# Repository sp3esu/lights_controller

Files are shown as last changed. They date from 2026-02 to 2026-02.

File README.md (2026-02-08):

# RC Light Controller

Wireless light controller for RC cars and trucks. A touchscreen handheld remote (TX) communicates over ESP-NOW with a receiver (RX) mounted on the vehicle to control multiple light outputs in real time.

## Translations

- [Polski (PL)](docs/README_PL.md)
- [Deutsch (DE)](docs/README_DE.md)
- [Francais (FR)](docs/README_FR.md)
- [Русский (RU)](docs/README_RU.md)
- [Українська (UA)](docs/README_UA.md)

## Features

- **5 independent light channels**: low beam, high beam, fog lights, light bar, hazard lights
- **Touchscreen UI**: 2x3 button grid on a 1.47" color display with LVGL
- **ESP-NOW wireless**: low-latency, connectionless protocol — no WiFi router needed
- **Automatic pairing**: one-button pairing with persistent NVS storage
- **Safety interlocks**: high beam requires low beam; failsafe shuts off all lights after 30s without signal
- **Connection monitoring**: heartbeats, ACK-based command confirmation, NeoPixel status LED
- **Test mode**: controller works standalone for UI testing without a receiver

## Hardware

### Controller (TX)

| Component | Details |
|---|---|
| Board | [Waveshare ESP32-C6-Touch-LCD-1.47-M](https://www.waveshare.com/wiki/ESP32-C6-Touch-LCD-1.47) |
| MCU | ESP32-C6 (RISC-V, 8 MB flash) |
| Display | 1.47" JD9853, 172x320, rotated to 320x172 landscape |
| Touch | AXS5106L capacitive (I2C @ 0x63) |
| Status LED | WS2812 NeoPixel on GPIO8 |

### Receiver (RX)

| Component | Details |
|---|---|
| Board | Any ESP32 dev board (classic Xtensa) |
| Light outputs | 5x GPIO, active-HIGH |
| Status LED | Built-in LED on GPIO2 |
| Pairing | BOOT button (GPIO0) — hold during power-up |

### Receiver Wiring

Connect ESP32 GPIOs to your lights through appropriate drivers (MOSFETs, relays, or LED drivers) depending on voltage and current requirements. All outputs are active-HIGH (3.3 V logic).

| GPIO | Function |
|---|---|
| 16 | Fog lights |
| 17 | Low beam |
| 18 | High beam |
| 19 | Light bar |
| 21 | Hazard lights |
| 2 | Status LED |
| 0 | Pairing button (BOOT) |

## Building & Flashing

### Prerequisites

- [PlatformIO](https://platformio.org/) (CLI or IDE plugin)
- USB cables for both boards

### Build

```bash
# Build controller (TX) firmware
pio run -e controller

# Build receiver (RX) firmware
pio run -e receiver
```

### Flash

```bash
# Flash controller
pio run -e controller -t upload

# Flash receiver
pio run -e receiver -t upload
```

### Serial Monitor

```bash
pio device monitor    # 115200 baud
```

## Pairing

1. Power on the **receiver** while holding the **BOOT button** (GPIO0). The status LED flashes 3 times to confirm pairing mode.
2. On the **controller**, open **Settings** and tap **Start Pairing**.
3. Both devices exchange MAC addresses over ESP-NOW broadcast and store them in NVS.
4. Power-cycle both devices. The pairing is persistent and survives reboots.

## Protocol

Communication uses ESP-NOW with packed C structs (`__attribute__((packed))`) for cross-architecture compatibility (RISC-V controller / Xtensa receiver).

| Message | Direction | Purpose |
|---|---|---|
| `LightCommand` | TX -> RX | Set light state (5-bit bitmask) |
| `LightAck` | RX -> TX | Confirm current state |
| `Heartbeat` | RX -> TX | Keep-alive (every 2 s) |
| `StateReport` | RX -> TX | Full state + uptime |
| `PairRequest` | TX -> RX | Broadcast pairing request |
| `PairResponse` | RX -> TX | Pairing response with MAC |

### Light Bitmask

| Bit | Light |
|-----|---|
| 0 | Fog lights |
| 1 | Low beam |
| 2 | High beam |
| 3 | Light bar |
| 4 | Hazard lights |

### Timing

| Parameter | Value |
|---|---|
| ACK timeout | 200 ms |
| Max retries | 3 |
| Heartbeat interval | 2 s |
| Connection timeout (TX) | 6 s |
| Failsafe timeout (RX) | 30 s |

## Project Structure

```
light_controller/
├── src/
│   ├── controller/      # TX: display, touch, LVGL UI, ESP-NOW TX
│   └── receiver/        # RX: GPIO outputs, ESP-NOW RX, failsafe
├── lib/
│   ├── protocol/        # Shared wire protocol definitions
│   └── axs5106l_touch/  # AXS5106L touch driver
├── include/
│   └── lv_conf.h        # LVGL 8.4 configuration
└── platformio.ini       # Build configuration (two environments)
```

## Dependencies

### Controller
- [LVGL 8.4](https://lvgl.io/) — touchscreen UI framework
- [Arduino_GFX 1.6.5](https://github.com/moononournation/Arduino_GFX) — display driver
- [FastLED 3.9](https://fastled.io/) — NeoPixel status LED

### Receiver
- ESP-IDF built-ins only (ESP-NOW, WiFi, Preferences)

## License

This project is open source. See [LICENSE](LICENSE) for details.

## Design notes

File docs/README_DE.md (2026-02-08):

# RC-Lichtsteuerung

[English](../README.md) | [Polski](README_PL.md) | **Deutsch** | [Francais](README_FR.md) | [Русский](README_RU.md) | [Українська](README_UA.md)

Kabellose Lichtsteuerung fuer RC-Autos und -Trucks. Eine Touchscreen-Fernbedienung (TX) kommuniziert ueber ESP-NOW mit einem am Fahrzeug montierten Empfaenger (RX) zur Echtzeit-Steuerung mehrerer Lichtausgaenge.

## Funktionen

- **5 unabhaengige Lichtkanaele**: Abblendlicht, Fernlicht, Nebelscheinwerfer, Lichtleiste, Warnblinker
- **Touchscreen-Oberflaeche**: 2x3-Tastenraster auf einem 1,47"-Farbdisplay mit LVGL
- **ESP-NOW-Funk**: Protokoll mit geringer Latenz — kein WLAN-Router erforderlich
- **Automatisches Pairing**: Ein-Tasten-Kopplung mit dauerhafter NVS-Speicherung
- **Sicherheitsverriegelungen**: Fernlicht erfordert Abblendlicht; Failsafe schaltet alle Lichter nach 30 s ohne Signal ab
- **Verbindungsueberwachung**: Heartbeats, ACK-basierte Befehlsbestaetigung, NeoPixel-Status-LED
- **Testmodus**: Controller funktioniert eigenstaendig ohne Empfaenger

## Hardware

### Controller (TX)

| Komponente | Details |
|---|---|
| Platine | [Waveshare ESP32-C6-Touch-LCD-1.47-M](https://www.waveshare.com/wiki/ESP32-C6-Touch-LCD-1.47) |
| MCU | ESP32-C6 (RISC-V, 8 MB Flash) |
| Display | 1,47" JD9853, 172x320, auf 320x172 Querformat gedreht |
| Touch | AXS5106L kapazitiv (I2C @ 0x63) |
| Status-LED | WS2812 NeoPixel an GPIO8 |

### Empfaenger (RX)

| Komponente | Details |
|---|---|
| Platine | Beliebiges ESP32-Entwicklungsboard (klassisches Xtensa) |
| Lichtausgaenge | 5x GPIO, aktiv-HIGH |
| Status-LED | Eingebaute LED an GPIO2 |
| Pairing | BOOT-Taste (GPIO0) — beim Einschalten gedrueckt halten |

### Empfaenger-Verkabelung

Verbinden Sie die ESP32-GPIOs ueber geeignete Treiber (MOSFETs, Relais oder LED-Treiber) mit Ihren Lichtern, je nach Spannungs- und Stromanforderungen. Alle Ausgaenge sind aktiv-HIGH (3,3-V-Logik).

| GPIO | Funktion |
|---|---|
| 16 | Nebelscheinwerfer |
| 17 | Abblendlicht |
| 18 | Fernlicht |
| 19 | Lichtleiste |
| 21 | Warnblinker |
| 2 | Status-LED |
| 0 | Pairing-Taste (BOOT) |

## Kompilieren & Flashen

### Voraussetzungen

- [PlatformIO](https://platformio.org/) (CLI oder IDE-Plugin)
- USB-Kabel fuer beide Platinen

### Kompilieren

```bash
# Controller-Firmware (TX) kompilieren
pio run -e controller

# Empfaenger-Firmware (RX) kompilieren
pio run -e receiver
```

### Flashen

```bash
# Controller flashen
pio run -e controller -t upload

# Empfaenger flashen
pio run -e receiver -t upload
```

### Serieller Monitor

```bash
pio device monitor    # 115200 Baud
```

## Pairing

1. Schalten Sie den **Empfaenger** ein und halten Sie dabei die **BOOT-Taste** (GPIO0) gedrueckt. Die Status-LED blinkt 3 Mal zur Bestaetigung des Pairing-Modus.
2. Oeffnen Sie auf dem **Controller** die **Einstellungen** und tippen Sie auf **Pairing starten**.
3. Beide Geraete tauschen MAC-Adressen ueber ESP-NOW-Broadcast aus und speichern sie im NVS.
4. Starten Sie beide Geraete neu. Das Pairing ist dauerhaft und uebersteht Neustarts.

## Protokoll

Die Kommunikation verwendet ESP-NOW mit gepackten C-Structs (`__attribute__((packed))`) fuer architekturuebergreifende Kompatibilitaet (RISC-V-Controller / Xtensa-Empfaenger).

| Nachricht | Richtung | Zweck |
|---|---|---|
| `LightCommand` | TX -> RX | Lichtzustand setzen (5-Bit-Maske) |
| `LightAck` | RX -> TX | Aktuellen Zustand bestaetigen |
| `Heartbeat` | RX -> TX | Verbindungserhaltung (alle 2 s) |
| `StateReport` | RX -> TX | Vollstaendiger Zustand + Betriebszeit |
| `PairRequest` | TX -> RX | Pairing-Anfrage (Broadcast) |
| `PairResponse` | RX -> TX | Pairing-Antwort mit MAC |

### Licht-Bitmaske

| Bit | Licht |
|-----|---|
| 0 | Nebelscheinwerfer |
| 1 | Abblendlicht |
| 2 | Fernlicht |
| 3 | Lichtleiste |
| 4 | Warnblinker |

### Zeitvorgaben

| Parameter | Wert |
|---|---|
| ACK-Timeout | 200 ms |
| Max. Wiederholungen | 3 |
| Heartbeat-Intervall | 2 s |
| Verbindungs-Timeout (TX) | 6 s |
| Failsafe-Timeout (RX) | 30 s |

## Projektstruktur

```
light_controller/
├── src/
│   ├── controller/      # TX: Display, Touch, LVGL-UI, ESP-NOW TX
│   └── receiver/        # RX: GPIO-Ausgaenge, ESP-NOW RX, Failsafe
├── lib/
│   ├── protocol/        # Gemeinsame Protokolldefinitionen
│   └── axs5106l_touch/  # AXS5106L-Touch-Treiber
├── include/
│   └── lv_conf.h        # LVGL 8.4 Konfiguration
└── platformio.ini       # Build-Konfiguration (zwei Umgebungen)
```

## Abhaengigkeiten

### Controller
- [LVGL 8.4](https://lvgl.io/) — Touchscreen-UI-Framework
- [Arduino_GFX 1.6.5](https://github.com/moononournation/Arduino_GFX) — Display-Treiber
- [FastLED 3.9](https://fastled.io/) — NeoPixel-Status-LED

### Empfaenger
- Nur ESP-IDF-Bordmittel (ESP-NOW, WiFi, Preferences)

## Lizenz

Dieses Projekt ist Open Source. Details siehe [LICENSE](../LICENSE).

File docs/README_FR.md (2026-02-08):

# Controleur d'eclairage RC

[English](../README.md) | [Polski](README_PL.md) | [Deutsch](README_DE.md) | **Francais** | [Русский](README_RU.md) | [Українська](README_UA.md)

Controleur d'eclairage sans fil pour voitures et camions RC. Une telecommande a ecran tactile (TX) communique via ESP-NOW avec un recepteur (RX) monte sur le vehicule pour controler plusieurs sorties lumineuses en temps reel.

## Fonctionnalites

- **5 canaux lumineux independants** : feux de croisement, feux de route, antibrouillards, barre lumineuse, feux de detresse
- **Interface tactile** : grille de boutons 2x3 sur un ecran couleur 1,47" avec LVGL
- **Communication ESP-NOW** : protocole a faible latence — aucun routeur WiFi necessaire
- **Appairage automatique** : appairage en un bouton avec stockage persistant NVS
- **Verrouillages de securite** : les feux de route necessitent les feux de croisement ; le mode securite eteint toutes les lumieres apres 30 s sans signal
- **Surveillance de connexion** : heartbeats, confirmation de commandes par ACK, LED NeoPixel de statut
- **Mode test** : le controleur fonctionne de maniere autonome sans recepteur

## Materiel

### Controleur (TX)

| Composant | Details |
|---|---|
| Carte | [Waveshare ESP32-C6-Touch-LCD-1.47-M](https://www.waveshare.com/wiki/ESP32-C6-Touch-LCD-1.47) |
| MCU | ESP32-C6 (RISC-V, 8 Mo flash) |
| Ecran | 1,47" JD9853, 172x320, pivote en 320x172 paysage |
| Tactile | AXS5106L capacitif (I2C @ 0x63) |
| LED de statut | WS2812 NeoPixel sur GPIO8 |

### Recepteur (RX)

| Composant | Details |
|---|---|
| Carte | Toute carte de developpement ESP32 (Xtensa classique) |
| Sorties lumineuses | 5x GPIO, actif-HAUT |
| LED de statut | LED integree sur GPIO2 |
| Appairage | Bouton BOOT (GPIO0) — maintenir a l'allumage |

### Cablage du recepteur

Connectez les GPIO de l'ESP32 a vos lumieres via des pilotes appropries (MOSFETs, relais ou pilotes LED) selon les exigences de tension et de courant. Toutes les sorties sont actif-HAUT (logique 3,3 V).

| GPIO | Fonction |
|---|---|
| 16 | Antibrouillards |
| 17 | Feux de croisement |
| 18 | Feux de route |
| 19 | Barre lumineuse |
| 21 | Feux de detresse |
| 2 | LED de statut |
| 0 | Bouton d'appairage (BOOT) |

## Compilation et flashage

### Prerequis

- [PlatformIO](https://platformio.org/) (CLI ou plugin IDE)
- Cables USB pour les deux cartes

### Compilation

```bash
# Compiler le firmware du controleur (TX)
pio run -e controller

# Compiler le firmware du recepteur (RX)
pio run -e receiver
```

### Flashage

```bash
# Flasher le controleur
pio run -e controller -t upload

# Flasher le recepteur
pio run -e receiver -t upload
```

### Moniteur serie

```bash
pio device monitor    # 115200 bauds
```

## Appairage

1. Allumez le **recepteur** en maintenant le **bouton BOOT** (GPIO0). La LED de statut clignote 3 fois pour confirmer le mode d'appairage.
2. Sur le **controleur**, ouvrez les **Parametres** et appuyez sur **Demarrer l'appairage**.
3. Les appareils echangent leurs adresses MAC via broadcast ESP-NOW et les stockent en NVS.
4. Redemarrez les deux appareils. L'appairage est persistant et survit aux redemarrages.

## Protocole

La communication utilise ESP-NOW avec des structures C compactees (`__attribute__((packed))`) pour la compatibilite inter-architectures (controleur RISC-V / recepteur Xtensa).

| Message | Direction | Fonction |
|---|---|---|
| `LightCommand` | TX -> RX | Definir l'etat des lumieres (masque 5 bits) |
| `LightAck` | RX -> TX | Confirmer l'etat actuel |
| `Heartbeat` | RX -> TX | Maintien de connexion (toutes les 2 s) |
| `StateReport` | RX -> TX | Etat complet + duree de fonctionnement |
| `PairRequest` | TX -> RX | Demande d'appairage (broadcast) |
| `PairResponse` | RX -> TX | Reponse d'appairage avec MAC |

### Masque binaire des lumieres

| Bit | Lumiere |
|-----|---|
| 0 | Antibrouillards |
| 1 | Feux de croisement |
| 2 | Feux de route |
| 3 | Barre lumineuse |
| 4 | Feux de detresse |

### Temporisations

| Parametre | Valeur |
|---|---|
| Timeout ACK | 200 ms |
| Essais max. | 3 |
| Intervalle heartbeat | 2 s |
| Timeout de connexion (TX) | 6 s |
| Timeout de securite (RX) | 30 s |

## Structure du projet

```
light_controller/
├── src/
│   ├── controller/      # TX : ecran, tactile, UI LVGL, ESP-NOW TX
│   └── receiver/        # RX : sorties GPIO, ESP-NOW RX, mode securite
├── lib/
│   ├── protocol/        # Definitions de protocole partagees
│   └── axs5106l_touch/  # Pilote tactile AXS5106L
├── include/
│   └── lv_conf.h        # Configuration LVGL 8.4
└── platformio.ini       # Configuration de compilation (deux environnements)
```

## Dependances

### Controleur
- [LVGL 8.4](https://lvgl.io/) — framework d'interface tactile
- [Arduino_GFX 1.6.5](https://github.com/moononournation/Arduino_GFX) — pilote d'ecran
- [FastLED 3.9](https://fastled.io/) — LED NeoPixel de statut

### Recepteur
- Uniquement les composants integres ESP-IDF (ESP-NOW, WiFi, Preferences)

## Licence

Ce projet est open source. Voir [LICENSE](../LICENSE) pour les details.

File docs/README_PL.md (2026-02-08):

# Kontroler Oswietlenia RC

[English](../README.md) | **Polski** | [Deutsch](README_DE.md) | [Francais](README_FR.md) | [Русский](README_RU.md) | [Українська](README_UA.md)

Bezprzewodowy kontroler oswietlenia do samochodow i ciezarowek RC. Reczny pilot z ekranem dotykowym (TX) komunikuje sie przez ESP-NOW z odbiornikiem (RX) zamontowanym w pojezdzie, sterujac wieloma wyjsciami swietlnymi w czasie rzeczywistym.

## Funkcje

- **5 niezaleznych kanalow swiatla**: swiatla mijania, swiatla drogowe, swiatla przeciwmgielne, listwa swietlna, swiatla awaryjne
- **Interfejs dotykowy**: siatka przyciskow 2x3 na kolorowym wyswietlaczu 1,47" z LVGL
- **Lacznosc bezprzewodowa ESP-NOW**: protokol o niskim opoznieniu, bez potrzeby routera WiFi
- **Automatyczne parowanie**: parowanie jednym przyciskiem z trwalym zapisem w NVS
- **Blokady bezpieczenstwa**: swiatla drogowe wymagaja wlaczonych swiatel mijania; tryb awaryjny wylacza wszystkie swiatla po 30 s bez sygnalu
- **Monitorowanie polaczenia**: heartbeaty, potwierdzenia ACK, dioda LED NeoPixel
- **Tryb testowy**: kontroler dziala samodzielnie bez odbiornika

## Sprzet

### Kontroler (TX)

| Element | Szczegoly |
|---|---|
| Plytka | [Waveshare ESP32-C6-Touch-LCD-1.47-M](https://www.waveshare.com/wiki/ESP32-C6-Touch-LCD-1.47) |
| MCU | ESP32-C6 (RISC-V, 8 MB flash) |
| Wyswietlacz | 1,47" JD9853, 172x320, obrocony do 320x172 poziomo |
| Dotyk | AXS5106L pojemnosciowy (I2C @ 0x63) |
| Dioda statusu | WS2812 NeoPixel na GPIO8 |

### Odbiornik (RX)

| Element | Szczegoly |
|---|---|
| Plytka | Dowolna plytka ESP32 (klasyczny Xtensa) |
| Wyjscia swiatla | 5x GPIO, aktywne-WYSOKO |
| Dioda statusu | Wbudowana LED na GPIO2 |
| Parowanie | Przycisk BOOT (GPIO0) — przytrzymaj przy wlaczaniu |

### Polaczenia odbiornika

Podlacz GPIO ESP32 do swiatel przez odpowiednie sterowniki (MOSFET-y, przekazniki lub sterowniki LED) w zaleznosci od napiecia i pradu. Wszystkie wyjscia sa aktywne-WYSOKO (logika 3,3 V).

| GPIO | Funkcja |
|---|---|
| 16 | Swiatla przeciwmgielne |
| 17 | Swiatla mijania |
| 18 | Swiatla drogowe |
| 19 | Listwa swietlna |
| 21 | Swiatla awaryjne |
| 2 | Dioda statusu |
| 0 | Przycisk parowania (BOOT) |

## Kompilacja i programowanie

### Wymagania

- [PlatformIO](https://platformio.org/) (CLI lub wtyczka IDE)
- Kable USB do obu plytek

### Kompilacja

```bash
# Kompilacja firmware kontrolera (TX)
pio run -e controller

# Kompilacja firmware odbiornika (RX)
pio run -e receiver
```

### Programowanie

```bash
# Programowanie kontrolera
pio run -e controller -t upload

# Programowanie odbiornika
pio run -e receiver -t upload
```

### Monitor szeregowy

```bash
pio device monitor    # 115200 baud
```

## Parowanie

1. Wlacz **odbiornik** przytrzymujac **przycisk BOOT** (GPIO0). Dioda statusu mrugnie 3 razy potwierdzajac tryb parowania.
2. Na **kontrolerze** wejdz w **Ustawienia** i dotknij **Rozpocznij parowanie**.
3. Urzadzenia wymieniaja adresy MAC przez broadcast ESP-NOW i zapisuja je w NVS.
4. Zrestartuj oba urzadzenia. Parowanie jest trwale i przetrwa ponowne uruchomienie.

## Protokol

Komunikacja uzywa ESP-NOW z upakowanymi strukturami C (`__attribute__((packed))`) dla kompatybilnosci miedzy architekturami (RISC-V kontroler / Xtensa odbiornik).

| Wiadomosc | Kierunek | Cel |
|---|---|-----|
| `LightCommand` | TX -> RX | Ustaw stan swiatel (maska 5-bitowa) |
| `LightAck` | RX -> TX | Potwierdz aktualny stan |
| `Heartbeat` | RX -> TX | Podtrzymanie polaczenia (co 2 s) |
| `StateReport` | RX -> TX | Pelny stan + czas pracy |
| `PairRequest` | TX -> RX | Zadanie parowania (broadcast) |
| `PairResponse` | RX -> TX | Odpowiedz parowania z MAC |

### Maska bitowa swiatel

| Bit | Swiatlo |
|-----|---|
| 0 | Swiatla przeciwmgielne |
| 1 | Swiatla mijania |
| 2 | Swiatla drogowe |
| 3 | Listwa swietlna |
| 4 | Swiatla awaryjne |

### Czasy

| Parametr | Wartosc |
|---|---|
| Timeout ACK | 200 ms |
| Maks. powtorzen | 3 |
| Interwal heartbeat | 2 s |
| Timeout polaczenia (TX) | 6 s |
| Timeout awaryjny (RX) | 30 s |

## Struktura projektu

```
light_controller/
├── src/
│   ├── controller/      # TX: wyswietlacz, dotyk, UI LVGL, ESP-NOW TX
│   └── receiver/        # RX: wyjscia GPIO, ESP-NOW RX, tryb awaryjny
├── lib/
│   ├── protocol/        # Wspoldzielone definicje protokolu
│   └── axs5106l_touch/  # Sterownik dotyku AXS5106L
├── include/
│   └── lv_conf.h        # Konfiguracja LVGL 8.4
└── platformio.ini       # Konfiguracja kompilacji (dwa srodowiska)
```

## Zaleznosci

### Kontroler
- [LVGL 8.4](https://lvgl.io/) — framework UI ekranu dotykowego
- [Arduino_GFX 1.6.5](https://github.com/moononournation/Arduino_GFX) — sterownik wyswietlacza
- [FastLED 3.9](https://fastled.io/) — dioda statusu NeoPixel

### Odbiornik
- Tylko wbudowane komponenty ESP-IDF (ESP-NOW, WiFi, Preferences)

## Licencja

Ten projekt jest open source. Szczegoly w pliku [LICENSE](../LICENSE).

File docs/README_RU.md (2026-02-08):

# Контроллер освещения RC

[English](../README.md) | [Polski](README_PL.md) | [Deutsch](README_DE.md) | [Francais](README_FR.md) | **Русский** | [Українська](README_UA.md)

Беспроводной контроллер освещения для RC-автомобилей и грузовиков. Ручной пульт с сенсорным экраном (TX) связывается через ESP-NOW с приёмником (RX), установленным на модели, для управления несколькими световыми выходами в реальном времени.

## Возможности

- **5 независимых световых каналов**: ближний свет, дальний свет, противотуманные фары, световая балка, аварийная сигнализация
- **Сенсорный интерфейс**: сетка кнопок 2x3 на цветном дисплее 1,47" с LVGL
- **Беспроводная связь ESP-NOW**: протокол с низкой задержкой — WiFi-роутер не нужен
- **Автоматическое сопряжение**: сопряжение одной кнопкой с сохранением в NVS
- **Блокировки безопасности**: дальний свет требует включённого ближнего; аварийный режим выключает все огни через 30 с без сигнала
- **Мониторинг соединения**: heartbeat-ы, подтверждение команд через ACK, статусный NeoPixel
- **Тестовый режим**: контроллер работает автономно без приёмника

## Оборудование

### Контроллер (TX)

| Компонент | Описание |
|---|---|
| Плата | [Waveshare ESP32-C6-Touch-LCD-1.47-M](https://www.waveshare.com/wiki/ESP32-C6-Touch-LCD-1.47) |
| MCU | ESP32-C6 (RISC-V, 8 МБ flash) |
| Дисплей | 1,47" JD9853, 172x320, повёрнут в 320x172 альбомную ориентацию |
| Тач | AXS5106L ёмкостный (I2C @ 0x63) |
| Статусный LED | WS2812 NeoPixel на GPIO8 |

### Приёмник (RX)

| Компонент | Описание |
|---|---|
| Плата | Любая плата ESP32 (классический Xtensa) |
| Световые выходы | 5x GPIO, активный-ВЫСОКИЙ |
| Статусный LED | Встроенный LED на GPIO2 |
| Сопряжение | Кнопка BOOT (GPIO0) — удерживать при включении |

### Подключение приёмника

Подключите GPIO ESP32 к вашим огням через подходящие драйверы (MOSFET-ы, реле или LED-драйверы) в зависимости от напряжения и тока. Все выходы активны при высоком уровне (логика 3,3 В).

| GPIO | Функция |
|---|---|
| 16 | Противотуманные фары |
| 17 | Ближний свет |
| 18 | Дальний свет |
| 19 | Световая балка |
| 21 | Аварийная сигнализация |
| 2 | Статусный LED |
| 0 | Кнопка сопряжения (BOOT) |

## Сборка и прошивка

### Требования

- [PlatformIO](https://platformio.org/) (CLI или плагин для IDE)
- USB-кабели для обеих плат

### Сборка

```bash
# Сборка прошивки контроллера (TX)
pio run -e controller

# Сборка прошивки приёмника (RX)
pio run -e receiver
```

### Прошивка

```bash
# Прошить контроллер
pio run -e controller -t upload

# Прошить приёмник
pio run -e receiver -t upload
```

### Последовательный монитор

```bash
pio device monitor    # 115200 бод
```

## Сопряжение

1. Включите **приёмник**, удерживая **кнопку BOOT** (GPIO0). Статусный LED мигнёт 3 раза, подтверждая режим сопряжения.
2. На **контроллере** откройте **Настройки** и нажмите **Начать сопряжение**.
3. Устройства обмениваются MAC-адресами через ESP-NOW broadcast и сохраняют их в NVS.
4. Перезагрузите оба устройства. Сопряжение сохраняется и переживает перезагрузки.

## Протокол

Связь использует ESP-NOW с упакованными C-структурами (`__attribute__((packed))`) для кросс-архитектурной совместимости (RISC-V контроллер / Xtensa приёмник).

| Сообщение | Направление | Назначение |
|---|---|---|
| `LightCommand` | TX -> RX | Задать состояние огней (5-битная маска) |
| `LightAck` | RX -> TX | Подтвердить текущее состояние |
| `Heartbeat` | RX -> TX | Поддержание связи (каждые 2 с) |
| `StateReport` | RX -> TX | Полное состояние + время работы |
| `PairRequest` | TX -> RX | Запрос сопряжения (broadcast) |
| `PairResponse` | RX -> TX | Ответ сопряжения с MAC |

### Битовая маска огней

| Бит | Свет |
|-----|---|
| 0 | Противотуманные фары |
| 1 | Ближний свет |
| 2 | Дальний свет |
| 3 | Световая балка |
| 4 | Аварийная сигнализация |

### Тайминги

| Параметр | Значение |
|---|---|
| Таймаут ACK | 200 мс |
| Макс. повторов | 3 |
| Интервал heartbeat | 2 с |
| Таймаут соединения (TX) | 6 с |
| Таймаут аварийного режима (RX) | 30 с |

## Структура проекта

```
light_controller/
├── src/
│   ├── controller/      # TX: дисплей, тач, LVGL UI, ESP-NOW TX
│   └── receiver/        # RX: GPIO-выходы, ESP-NOW RX, аварийный режим
├── lib/
│   ├── protocol/        # Общие определения протокола
│   └── axs5106l_touch/  # Драйвер тача AXS5106L
├── include/
│   └── lv_conf.h        # Конфигурация LVGL 8.4
└── platformio.ini       # Конфигурация сборки (два окружения)
```

## Зависимости

### Контроллер
- [LVGL 8.4](https://lvgl.io/) — фреймворк сенсорного UI
- [Arduino_GFX 1.6.5](https://github.com/moononournation/Arduino_GFX) — драйвер дисплея
- [FastLED 3.9](https://fastled.io/) — статусный NeoPixel

### Приёмник
- Только встроенные компоненты ESP-IDF (ESP-NOW, WiFi, Preferences)

## Лицензия

Этот проект с открытым исходным кодом. Подробности в файле [LICENSE](../LICENSE).

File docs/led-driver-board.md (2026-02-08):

# LED Driver Board — Design & Assembly Guide

Dedicated PCB for driving RC car LEDs from ESP32 GPIOs via MOSFET low-side switching.

## Overview

```
3S LiPo (11.1V) ──┬── MP1584EN buck ── 5V ── ESP32 Vin
                   │
                   └── Battery+ to LED channels (via resistor+LED off-board)
                        │
                   AO3400A MOSFETs (low-side switch, gate driven by ESP32 GPIO)
                        │
                       GND
```

- **9 output channels** — MOSFET-switched ground for each LED group
- **On-board 5V buck** — powers ESP32 dev board via Vin pin
- **LED resistors mounted near LEDs** (off-board) — keeps PCB small, allows per-LED tuning
- **ESP32 dev board plugs in via pin headers** — no USB/boot circuitry on PCB

## Power Supply

**Input:** 3S LiPo (11.1V nominal, 9.9V–12.6V range)

**On-board regulation:**

| Stage | Converter | Input | Output | Notes |
|---|---|---|---|---|
| 1 | MP1584EN buck module | 9.9–12.6V | 5V | ~92% efficient, powers ESP32 |
| 2 | ESP32 onboard LDO | 5V (Vin pin) | 3.3V | Internal to dev board |

**MP1584EN module pinout:**

| Pin | Connection |
|-----|---|
| IN+ | Battery + (via screw terminal) |
| IN- | GND |
| OUT+ | ESP32 Vin |
| OUT- | GND |

Adjust the trimpot to 5.0V **before** connecting the ESP32.

## Channel Allocation

| Ch | GPIO | Function | LED Color | Typical LEDs | Resistor (20mA @ 11.1V) |
|----|---|---|---|---|---|
| 1 | 16 | Low beam | White | 2 (parallel) | 390R 1/4W each |
| 2 | 17 | High beam | White | 2 (parallel) | 390R 1/4W each |
| 3 | 18 | Left turn | Amber | 3+ (parallel) | 470R 1/4W each |
| 4 | 19 | Right turn | Amber | 3+ (parallel) | 470R 1/4W each |
| 5 | 21 | Stop/brake | Red | 3+ (parallel) | 470R 1/4W each |
| 6 | 22 | Reverse | White | 1–2 (parallel) | 390R 1/4W each |
| 7 | 23 | Light bar | White | High current | Sized per strip |
| 8 | 25 | Spare 1 | Any | User choice | — |
| 9 | 26 | Spare 2 | Any | User choice | — |
| — | 2 | Status LED | — | On-board | On-board |

All GPIOs support hardware PWM (LEDC) on ESP32.

## Circuit Topology

### Per-channel schematic (low-side MOSFET switch)

```
Battery+ ──── [to off-board connector] ──── Resistor ──── LED(+) ──── LED(-) ──── [back to board]
                                                                                        │
                                                                                      Drain
                                                                                        │
                                                                                   AO3400A (N-ch)
                                                                                        │
                                                                                      Source
                                                                                        │
                                                                                       GND

ESP32 GPIO ──[100R]──── Gate
                          │
                        [10K]
                          │
                         GND
```

**Each output connector provides two pins:**
- **Pin 1:** Battery+ (always hot)
- **Pin 2:** MOSFET drain (switched ground)

The LED + current-limiting resistor are wired off-board between these two pins.

### Gate drive circuit

| Component | Value | Purpose |
|---|---|---|
| R_gate | 100R (0603) | Limits gate inrush current, dampens ringing |
| R_pulldown | 10K (0603) | Keeps MOSFET OFF during ESP32 boot/reset |

The 10K pull-down ensures all lights are OFF when the ESP32 is resetting or unprogrammed.

## MOSFET Selection: AO3400A

| Parameter | Value |
|---|---|
| Package | SOT-23 |
| Type | N-channel enhancement |
| Vds (max) | 30V |
| Id (max) | 5.7A |
| Rds(on) @ Vgs=4.5V | 32mΩ |
| Rds(on) @ Vgs=2.5V | 48mΩ |
| Vgs(th) | 0.65V typ, 1.05V max |
| LCSC # | C20917 |

At 3.3V gate drive from ESP32, the AO3400A is fully enhanced. Power dissipation at 20mA per LED is negligible (~0.01mW).

For the light bar channel (Ch 7), the AO3400A handles up to 5.7A — sufficient for LED strips.

## Resistor Calculations

### Formula

```
R = (V_supply - V_f) / I_target
```

Where:
- V_supply = 11.1V (nominal), range 9.9V–12.6V
- I_target = 20mA (standard 5mm LED)
- V_f = forward voltage of LED

### White LEDs (Vf ≈ 3.2V)

```
R = (11.1 - 3.2) / 0.020 = 395Ω → use 390R (standard value)
```

| Condition | Current |
|---|---|
| Full charge (12.6V) | 24.1mA |
| Nominal (11.1V) | 20.3mA |
| Low battery (9.9V) | 17.2mA |

### Red LEDs (Vf ≈ 2.0V)

```
R = (11.1 - 2.0) / 0.020 = 455Ω → use 470R (standard value)
```

| Condition | Current |
|---|---|
| Full charge (12.6V) | 22.6mA |
| Nominal (11.1V) | 19.4mA |
| Low battery (9.9V) | 16.8mA |

### Amber LEDs (Vf ≈ 2.1V)

```
R = (11.1 - 2.1) / 0.020 = 450Ω → use 470R (standard value)
```

| Condition | Current |
|---|---|
| Full charge (12.6V) | 22.3mA |
| Nominal (11.1V) | 19.1mA |
| Low battery (9.9V) | 16.6mA |

### Important notes

- **Each LED gets its own resistor** — parallel LEDs each have a dedicated series resistor
- **Do NOT put 3 white LEDs in series** — only 0.3V headroom at low battery (9.9V - 3×3.2V = 0.3V), LEDs will flicker and die
- **PWM dimming** works on top of the resistor — the resistor sets max current at 100% duty, PWM reduces average current proportionally
- **Resistor power:** P = I²R = 0.020² × 470 = 0.19W → 1/4W resistors are fine

## Connector Pinouts

### Power input (2-pin screw terminal, 5mm pitch)

| Pin | Signal |
|-----|---|
| 1 | Battery + (11.1V) |
| 2 | Battery - (GND) |

### LED output channels (JST-XH 2-pin per channel)

| Pin | Signal |
|-----|---|
| 1 | Battery + (always hot) |
| 2 | Switched GND (MOSFET drain) |

Wire LED + resistor between pin 1 and pin 2 (off-board).

### ESP32 dev board (2×15 or 2×19 pin headers, 2.54mm)

The ESP32 dev board plugs directly into female pin headers on the PCB. Only the following pins are actively used:

| ESP32 Pin | Board Connection |
|---|---|
| Vin | 5V from MP1584EN buck |
| GND | Common ground |
| GPIO 2 | Status LED (on-board) |
| GPIO 16 | Ch 1 MOSFET gate |
| GPIO 17 | Ch 2 MOSFET gate |
| GPIO 18 | Ch 3 MOSFET gate |
| GPIO 19 | Ch 4 MOSFET gate |
| GPIO 21 | Ch 5 MOSFET gate |
| GPIO 22 | Ch 6 MOSFET gate |
| GPIO 23 | Ch 7 MOSFET gate |
| GPIO 25 | Ch 8 MOSFET gate |
| GPIO 26 | Ch 9 MOSFET gate |

## PCB Specifications

| Parameter | Value |
|---|---|
| Dimensions | ~30 × 50 mm |
| Layers | 2 |
| Copper weight | 1 oz (35μm) |
| Min trace width | 0.25mm (signal), 0.5mm+ (power) |
| Min via | 0.3mm drill |
| Surface finish | HASL (lead-free) |

### Layout guidelines

- **Power traces** (battery, 5V): 0.5mm minimum, 1mm preferred
- **Light bar channel (Ch 7):** thicker traces or copper pour, screw terminal option for high current
- **Ground plane** on bottom layer — provides return path and heat dissipation
- **Decoupling caps** near MP1584EN: 22μF input, 22μF output (0805)
- **MOSFETs** placed in a row near board edge, close to output connectors
- **Pin headers** for ESP32 centered on board

## Bill of Materials

| # | Component | Qty | Package | LCSC # | ~Cost |
|---|---|-----|---|---|---|
| 1 | AO3400A N-ch MOSFET | 9 | SOT-23 | C20917 | $0.63 |
| 2 | 100R resistor (gate) | 9 | 0603 | C25803 | $0.09 |
| 3 | 10K resistor (pulldown) | 9 | 0603 | C25804 | $0.09 |
| 4 | MP1584EN buck module | 1 | Module | — | $0.50 |
| 5 | 22μF ceramic cap | 2 | 0805 | C45783 | $0.10 |
| 6 | JST-XH 2-pin header | 10 | Through-hole | C158012 | $1.50 |
| 7 | Female pin headers 1×15 | 2 | 2.54mm TH | C35445 | $0.20 |
| 8 | Screw terminal 2-pin | 1 | 5mm TH | C8465 | $0.15 |
| 9 | Status LED (green) | 1 | 0805 | C2297 | $0.02 |
| 10 | 1K resistor (status LED) | 1 | 0603 | C25585 | $0.01 |
| | **PCB (5 boards, JLCPCB)** | | | | **$2.00** |
| | **Total per board** | | | | **~$3–4** |

### Off-board components (per car)

| Component | Qty | Notes |
|---|-----|---|
| 390R 1/4W resistor | 6–8 | For white LEDs (low/high beam, reverse) |
| 470R 1/4W resistor | 9+ | For red/amber LEDs (turn, brake) |
| 5mm white LED | 6–8 | Headlights, reverse |
| 5mm amber LED | 6+ | Turn signals |
| 5mm red LED | 3+ | Brake/stop lights |
| JST-XH 2-pin housing + crimps | 9 | One per channel |

## Assembly Order

### Factory (JLCPCB SMD assembly)
1. All 0603 resistors (gate + pulldown)
2. All SOT-23 MOSFETs
3. 0805 capacitors
4. Status LED + resistor

### Hand-solder (after boards arrive)
1. Female pin headers for ESP32 (solder from bottom)
2. 2-pin screw terminal for battery input
3. JST-XH connectors for LED outputs
4. MP1584EN buck module (solder 4 pins)
5. **Set buck output to 5.0V** before inserting ESP32

### Testing
1. Connect battery, verify 5V output from buck
2. Insert ESP32, flash receiver firmware
3. Test each channel: measure voltage at JST output (should see battery voltage when GPIO high)
4. Connect test LED + resistor to each channel, verify operation
5. Test PWM dimming via serial commands or controller

## Design Tool

**Recommended: EasyEDA (Standard or Pro)**
- Free, browser-based
- LCSC component library (all parts above available)
- One-click BOM/pick-and-place export for JLCPCB assembly
- Direct order to JLCPCB

**Alternative: KiCad 9** — desktop, no vendor lock-in, steeper learning curve.

## Manufacturing

**JLCPCB** — ~$2 for 5 boards (2-layer, 30×50mm), SMD assembly ~$8–10 extra.

Order flow:
1. Export Gerber files from EasyEDA
2. Upload to jlcpcb.com
3. Select "SMD Assembly" and upload BOM + pick-and-place files
4. Review component placements
5. Order — 1–3 day production, ~2 week shipping to EU

## Reference Designs

- [Dubious Creations ESP32 8-ch LED controller](https://dubiouscreations.com/2020/08/16/building-an-esp32-light-controller/) — closest match, AO3400A MOSFETs, 20kHz PWM
- [TheDIYGuy999 RC Sound+Light ESP32](https://github.com/TheDIYGuy999/Rc_Engine_Sound_ESP32) — 12 channels, Eagle + Gerber files
- [Lane Boys MK4 RC Light Controller](https://github.com/laneboysrc/rc-light-controller) — TLC5940 constant-current approach

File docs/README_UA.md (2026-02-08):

# Контролер освiтлення RC

[English](../README.md) | [Polski](README_PL.md) | [Deutsch](README_DE.md) | [Francais](README_FR.md) | [Русский](README_RU.md) | **Українська**

Бездротовий контролер освiтлення для RC-автомобiлiв та вантажiвок. Ручний пульт з сенсорним екраном (TX) зв'язується через ESP-NOW з приймачем (RX), встановленим на моделi, для керування кiлькома свiтловими виходами в реальному часi.

## Можливостi

- **5 незалежних свiтлових каналiв**: ближнє свiтло, дальнє свiтло, протитуманнi фари, свiтлова балка, аварiйна сигналiзацiя
- **Сенсорний iнтерфейс**: сiтка кнопок 2x3 на кольоровому дисплеї 1,47" з LVGL
- **Бездротовий зв'язок ESP-NOW**: протокол з низькою затримкою — WiFi-роутер не потрiбен
- **Автоматичне сполучення**: сполучення однiєю кнопкою зi збереженням у NVS
- **Блокування безпеки**: дальнє свiтло потребує ввiмкненого ближнього; аварiйний режим вимикає всi вогнi через 30 с без сигналу
- **Монiторинг з'єднання**: heartbeat-и, пiдтвердження команд через ACK, статусний NeoPixel
- **Тестовий режим**: контролер працює автономно без приймача

## Обладнання

### Контролер (TX)

| Компонент | Опис |
|---|---|
| Плата | [Waveshare ESP32-C6-Touch-LCD-1.47-M](https://www.waveshare.com/wiki/ESP32-C6-Touch-LCD-1.47) |
| MCU | ESP32-C6 (RISC-V, 8 МБ flash) |
| Дисплей | 1,47" JD9853, 172x320, повернутий у 320x172 альбомну орiєнтацiю |
| Тач | AXS5106L ємнiсний (I2C @ 0x63) |
| Статусний LED | WS2812 NeoPixel на GPIO8 |

### Приймач (RX)

| Компонент | Опис |
|---|---|
| Плата | Будь-яка плата ESP32 (класичний Xtensa) |
| Свiтловi виходи | 5x GPIO, активний-ВИСОКИЙ |
| Статусний LED | Вбудований LED на GPIO2 |
| Сполучення | Кнопка BOOT (GPIO0) — утримувати при ввiмкненнi |

### Пiдключення приймача

Пiдключiть GPIO ESP32 до ваших вогнiв через вiдповiднi драйвери (MOSFET-и, реле або LED-драйвери) залежно вiд напруги та струму. Всi виходи активнi при високому рiвнi (логiка 3,3 В).

| GPIO | Функцiя |
|---|---|
| 16 | Протитуманнi фари |
| 17 | Ближнє свiтло |
| 18 | Дальнє свiтло |
| 19 | Свiтлова балка |
| 21 | Аварiйна сигналiзацiя |
| 2 | Статусний LED |
| 0 | Кнопка сполучення (BOOT) |

## Збiрка та прошивка

### Вимоги

- [PlatformIO](https://platformio.org/) (CLI або плагiн для IDE)
- USB-кабелi для обох плат

### Збiрка

```bash
# Збiрка прошивки контролера (TX)
pio run -e controller

# Збiрка прошивки приймача (RX)
pio run -e receiver
```

### Прошивка

```bash
# Прошити контролер
pio run -e controller -t upload

# Прошити приймач
pio run -e receiver -t upload
```

### Послiдовний монiтор

```bash
pio device monitor    # 115200 бод
```

## Сполучення

1. Увiмкнiть **приймач**, утримуючи **кнопку BOOT** (GPIO0). Статусний LED блимне 3 рази, пiдтверджуючи режим сполучення.
2. На **контролерi** вiдкрийте **Налаштування** та натиснiть **Почати сполучення**.
3. Пристрої обмiнюються MAC-адресами через ESP-NOW broadcast та зберiгають їх у NVS.
4. Перезавантажте обидва пристрої. Сполучення зберiгається i переживає перезавантаження.

## Протокол

Зв'язок використовує ESP-NOW з упакованими C-структурами (`__attribute__((packed))`) для крос-архiтектурної сумiсностi (RISC-V контролер / Xtensa приймач).

| Повiдомлення | Напрямок | Призначення |
|---|---|---|
| `LightCommand` | TX -> RX | Задати стан вогнiв (5-бiтна маска) |
| `LightAck` | RX -> TX | Пiдтвердити поточний стан |
| `Heartbeat` | RX -> TX | Пiдтримання зв'язку (кожнi 2 с) |
| `StateReport` | RX -> TX | Повний стан + час роботи |
| `PairRequest` | TX -> RX | Запит сполучення (broadcast) |
| `PairResponse` | RX -> TX | Вiдповiдь сполучення з MAC |

### Бiтова маска вогнiв

| Бiт | Свiтло |
|-----|---|
| 0 | Протитуманнi фари |
| 1 | Ближнє свiтло |
| 2 | Дальнє свiтло |
| 3 | Свiтлова балка |
| 4 | Аварiйна сигналiзацiя |

### Таймiнги

| Параметр | Значення |
|---|---|
| Таймаут ACK | 200 мс |
| Макс. повторiв | 3 |
| Iнтервал heartbeat | 2 с |
| Таймаут з'єднання (TX) | 6 с |
| Таймаут аварiйного режиму (RX) | 30 с |

## Структура проекту

```
light_controller/
├── src/
│   ├── controller/      # TX: дисплей, тач, LVGL UI, ESP-NOW TX
│   └── receiver/        # RX: GPIO-виходи, ESP-NOW RX, аварiйний режим
├── lib/
│   ├── protocol/        # Спiльнi визначення протоколу
│   └── axs5106l_touch/  # Драйвер тача AXS5106L
├── include/
│   └── lv_conf.h        # Конфiгурацiя LVGL 8.4
└── platformio.ini       # Конфiгурацiя збiрки (два оточення)
```

## Залежностi

### Контролер
- [LVGL 8.4](https://lvgl.io/) — фреймворк сенсорного UI
- [Arduino_GFX 1.6.5](https://github.com/moononournation/Arduino_GFX) — драйвер дисплея
- [FastLED 3.9](https://fastled.io/) — статусний NeoPixel

### Приймач
- Тiльки вбудованi компоненти ESP-IDF (ESP-NOW, WiFi, Preferences)

## Лiцензiя

Цей проект з вiдкритим вихiдним кодом. Деталi у файлi [LICENSE](../LICENSE).

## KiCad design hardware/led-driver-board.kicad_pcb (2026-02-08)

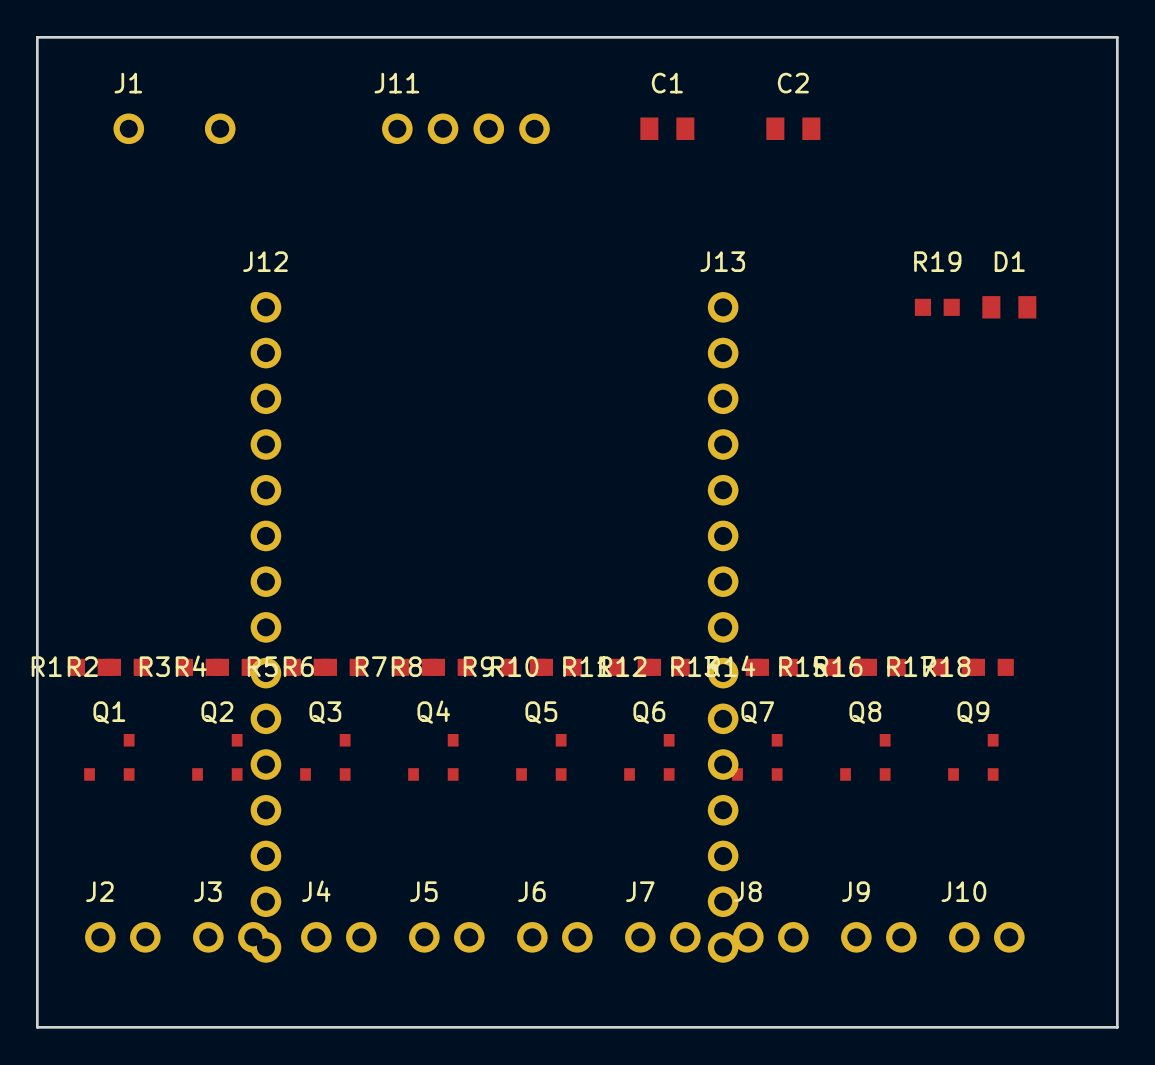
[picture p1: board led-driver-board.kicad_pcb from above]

Board: 2 copper layers, 60.0 x 55.0 mm, 44 parts (0 on the bottom side), 22 nets, no tracks yet.

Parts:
C1, C2: 22uF; C_0805_2012Metric
D1: Green; LED_0805_2012Metric
J1: Battery; TerminalBlock_bornier-2_P5.08mm
J2: Ch1; JST_XH_B2B-XH-A_1x02_P2.50mm_Vertical
J3: Ch2; JST_XH_B2B-XH-A_1x02_P2.50mm_Vertical
J4: Ch3; JST_XH_B2B-XH-A_1x02_P2.50mm_Vertical
J5: Ch4; JST_XH_B2B-XH-A_1x02_P2.50mm_Vertical
J6: Ch5; JST_XH_B2B-XH-A_1x02_P2.50mm_Vertical
J7: Ch6; JST_XH_B2B-XH-A_1x02_P2.50mm_Vertical
J8: Ch7; JST_XH_B2B-XH-A_1x02_P2.50mm_Vertical
J9: Ch8; JST_XH_B2B-XH-A_1x02_P2.50mm_Vertical
J10: Ch9; JST_XH_B2B-XH-A_1x02_P2.50mm_Vertical
J11: MP1584EN; PinHeader_1x04_P2.54mm_Vertical
J12: ESP32_Left; PinSocket_1x15_P2.54mm_Vertical
J13: ESP32_Right; PinSocket_1x15_P2.54mm_Vertical
Q1, Q2, Q3, Q4, Q5, Q6, Q7, Q8, Q9: AO3400A; SOT-23
R1, R3, R5, R7, R9, R11, R13, R15, R17: 100; R_0603_1608Metric
R2, R4, R6, R8, R10, R12, R14, R16, R18: 10K; R_0603_1608Metric
R19: 1K; R_0603_1608Metric

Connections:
+5V: C2.1, J11.3
+BATT: C1.1, J1.1, J2.1, J3.1, J4.1, J5.1, J6.1, J7.1, J8.1, J9.1, J10.1, J11.1
DRAIN_1: J2.2, Q1.3
DRAIN_2: J3.2, Q2.3
DRAIN_3: J4.2, Q3.3
DRAIN_4: J5.2, Q4.3
DRAIN_5: J6.2, Q5.3
DRAIN_6: J7.2, Q6.3
DRAIN_7: J8.2, Q7.3
DRAIN_8: J9.2, Q8.3
DRAIN_9: J10.2, Q9.3
GATE_1: Q1.1, R1.2, R2.1
GATE_2: Q2.1, R3.2, R4.1
GATE_3: Q3.1, R5.2, R6.1
GATE_4: Q4.1, R7.2, R8.1
GATE_5: Q5.1, R9.2, R10.1
GATE_6: Q6.1, R11.2, R12.1
GATE_7: Q7.1, R13.2, R14.1
GATE_8: Q8.1, R15.2, R16.1
GATE_9: Q9.1, R17.2, R18.1
GND: C1.2, C2.2, D1.2, J1.2, J11.2, J11.4, Q1.2, Q2.2, Q3.2, Q4.2, Q5.2, Q6.2, Q7.2, Q8.2, Q9.2, R2.2, R4.2, R6.2, R8.2, R10.2, R12.2, R14.2, R16.2, R18.2
STATUS_LED: D1.1, R19.2

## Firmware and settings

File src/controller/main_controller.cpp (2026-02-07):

#include <Arduino.h>
#include <FastLED.h>
#include "display.h"
#include "touch.h"
#include "ui.h"
#include "espnow_tx.h"

// WS2812 NeoPixel on GPIO8
#define PIN_NEOPIXEL 8
#define NUM_LEDS     1
static CRGB leds[NUM_LEDS];

// Pairing retry timer
static uint32_t last_pair_attempt = 0;
#define PAIR_RETRY_INTERVAL_MS 3000

static void on_ack(uint8_t light_state) {
    ui_set_light_state(light_state);
}

static void on_connection_change(bool connected) {
    ui_set_connection_status(connected);
    // Update NeoPixel
    leds[0] = connected ? CRGB::Green : CRGB::Red;
    FastLED.show();
}

void setup() {
    Serial.begin(115200);
    delay(100);
    Serial.println("RC Light Controller - TX");

    // Init NeoPixel
    FastLED.addLeds<WS2812, PIN_NEOPIXEL, GRB>(leds, NUM_LEDS);
    FastLED.setBrightness(20);
    leds[0] = CRGB::Blue;
    FastLED.show();

    // Init display + LVGL
    display_init();

    // Init touch input
    Arduino_GFX *gfx = display_get_gfx();
    touch_init(gfx->getRotation(), gfx->width(), gfx->height());

    // Init UI
    ui_init();

    // Init ESP-NOW
    espnow_tx_init();
    espnow_tx_set_ack_callback(on_ack);
    espnow_tx_set_connection_callback(on_connection_change);

    // Show appropriate screen
    if (espnow_tx_is_paired()) {
        ui_show_main();
        leds[0] = CRGB::Red;  // disconnected until first heartbeat
    } else {
        // No receiver paired - run in test mode so UI is usable
        ui_set_test_mode(true);
        ui_show_main();
        leds[0] = CRGB::Purple;
    }
    FastLED.show();

    Serial.println("Setup complete");
}

void loop() {
    // LVGL task handler
    lv_timer_handler();

    // ESP-NOW update (retries, heartbeat timeout)
    espnow_tx_update();

    // Once paired at runtime, switch from test mode to main
    if (espnow_tx_is_paired()) {
        static bool switched = false;
        if (!switched) {
            switched = true;
            ui_set_test_mode(false);
            ui_show_main();
        }
    }

    delay(5);
}

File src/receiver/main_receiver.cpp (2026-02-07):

#include <Arduino.h>
#include "lights.h"
#include "espnow_rx.h"
#include "protocol.h"

#define PIN_BOOT_BTN 0  // BOOT button for pairing mode

static bool failsafe_triggered = false;

static void on_light_command(uint8_t mask, uint8_t state) {
    lights_set(mask, state);
    failsafe_triggered = false;

    // Blink status LED
    digitalWrite(PIN_STATUS_LED, HIGH);
    delay(10);
    digitalWrite(PIN_STATUS_LED, LOW);
}

void setup() {
    Serial.begin(115200);
    delay(100);
    Serial.println("RC Light Controller - RX");

    lights_init();
    espnow_rx_init();
    espnow_rx_set_command_callback(on_light_command);

    // Check if BOOT button held during startup -> pairing mode
    pinMode(PIN_BOOT_BTN, INPUT_PULLUP);
    delay(100);
    if (digitalRead(PIN_BOOT_BTN) == LOW) {
        Serial.println("BOOT button held - entering pairing mode");
        espnow_rx_enter_pairing_mode();

        // Flash status LED to indicate pairing mode
        for (int i = 0; i < 6; i++) {
            digitalWrite(PIN_STATUS_LED, !digitalRead(PIN_STATUS_LED));
            delay(200);
        }
    }

    if (espnow_rx_is_paired()) {
        Serial.println("Paired and ready");
        digitalWrite(PIN_STATUS_LED, HIGH);
        delay(500);
        digitalWrite(PIN_STATUS_LED, LOW);
    } else {
        Serial.println("Not paired - hold BOOT button during startup to pair");
    }

    Serial.println("Setup complete");
}

void loop() {
    // Send heartbeats
    espnow_rx_update(lights_get_state());

    // Failsafe: turn off all lights if no command for FAILSAFE_TIMEOUT_MS
    if (!failsafe_triggered) {
        uint32_t elapsed = millis() - espnow_rx_last_command_time();
        if (elapsed >= FAILSAFE_TIMEOUT_MS && lights_get_state() != 0) {
            Serial.println("Failsafe: no commands received, lights off");
            lights_all_off();
            failsafe_triggered = true;
        }
    }

    delay(10);
}

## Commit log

2026-02-07 Initial commit: RC light controller with landscape dashboard fix
    Fix broken landscape layout in controller UI: use explicit pixel sizes
    (154x80) instead of LV_PCT(50) for 2x2 grid buttons, and remove
    lv_img_set_zoom() which doesn't work with alpha-8bit icons in LVGL v8.4.
    [display.cpp, display.h, espnow_rx.cpp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]
2026-02-08 Upgrade icons to 48x48 MDI SVGs and reverse button styling
    Replace hand-drawn 40x40 icons with anti-aliased 48x48 icons rasterized
    from Material Design Icons (fog, low beam, high beam) plus a custom light
    bar. OFF state now shows colored icon on transparent background; ON state
    shows dark icon on colored background. Add Python generation script.
    [generate_icons.py]
2026-02-08 Add hazard light, settings screen, and update UI to 2x3 grid
    - Add LIGHT_HAZARD bit (1<<4) to protocol and receiver GPIO (pin 21)
    - Expand controller UI from 2x2 to 2x3 button grid with hazard and settings buttons
    - Add hazard warning triangle and settings gear 48x48 icons
    - Add settings screen with pairing and back menu buttons
    - Swap fog/low beam button positions; change low beam color to green
    - Replace hand-drawn light bar icon with anti-aliased version
    [lights.cpp, lights.h]
2026-02-08 Make high beam depend on low beam being active
    High beam button appears disabled (dark gray, not clickable) when low beam
    is off. Turning off low beam while high beam is on automatically turns off
    high beam and sends the state to the receiver.
2026-02-08 Add LED driver board design and assembly documentation
2026-02-08 Fix KiCad files for KiCad 9.0 compatibility
    KiCad 9 enforces stricter parsing: all symbol/label (at x y) must
    include an explicit angle, and gr_rect must not have (fill ...).
    Updated generator and regenerated hardware files.
    [led-driver-board.kicad_pcb, led-driver-board.kicad_sch]
2026-02-08 Add KiCad local files and Python venv to .gitignore
2026-02-10 Convert receiver light outputs from digital to hardware PWM
    Replace digitalWrite with ESP32 LEDC PWM (5kHz, 8-bit) for all 5 light
    GPIOs. Existing bitmask API preserved for backward compatibility. New
    lights_set_level/lights_set_levels API enables arbitrary brightness control.
    [lights.cpp, lights.h]
2026-02-10 PWM lights output
